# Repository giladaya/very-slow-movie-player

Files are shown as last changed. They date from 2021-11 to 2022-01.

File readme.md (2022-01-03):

# Very Slow Movie Player

I was inspired by [this article](https://debugger.medium.com/how-to-build-a-very-slow-movie-player-in-2020-c5745052e4e4) which was inspired by [that article](https://medium.com/s/story/very-slow-movie-player-499f76c48b62) to build a VSMP.   However, I was put off by the cost of the hardware used in the original designs.  
Eventually found the LILYGO® TTGO T5-4.7 Inch E-paper ESP32 dev board which was cheap and easy to use, at the cost of settling for a smaller display.  
This repo includes the arduino sketch with some supporting info for making your own.

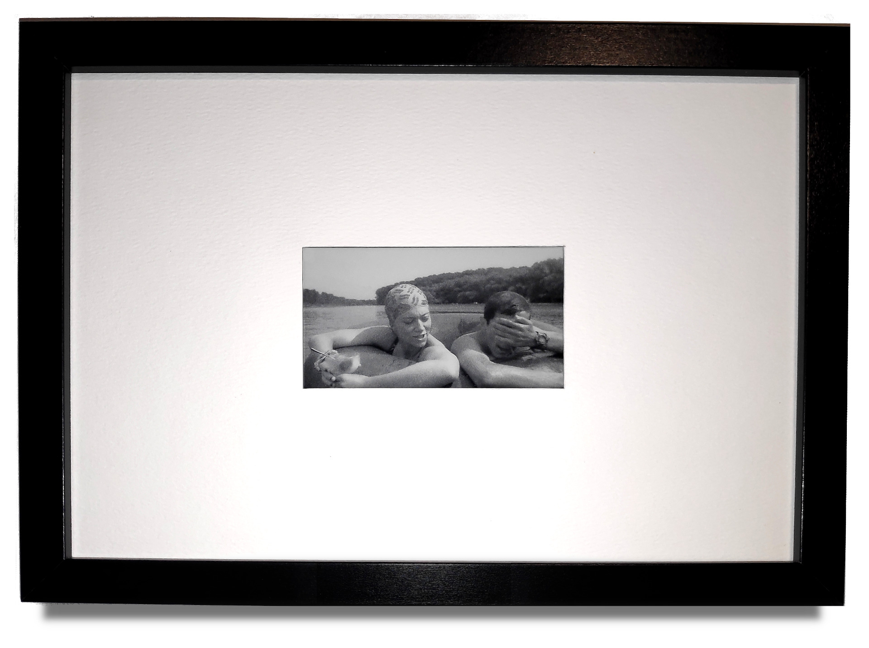
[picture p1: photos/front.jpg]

See photos folder for more photos.

## Features

- Long battery life  
  Uses deep sleep for efficient power use (actual battery life depends on the battery used)
- Resilient  
  The displayed frame position is saved to the SD card from time to time so playback can continue where it stopped after a reset or power loss
- Adaptive drawing  
  A special drawing procedure is used for dark frames for improved visual quality
- Self contained  
  Does not require a network connection or running a server
- Large capacity  
  Can hold hundreds of thousends of pictures (depending on the capacity of SD card used)
- Playlist support  
  Prepare a card with multiple movies by putting each one in a separate folder. They will be played by order one after the other

## Using

1. Setup your machine for development - see the instructions from [here](https://github.com/Xinyuan-LilyGO/LilyGo-EPD47)
2. Install [JPEGDEC library](https://github.com/bitbank2/JPEGDEC)
3. Adjust the configuration parameters at the top of the sketch file to your liking
4. Upload the sketch to the board
5. Prepare an SD card with the desired movies - see instructions below
6. Insert the SD card to the built-in reader
7. Connect a battery
8. Very slow playback of the movies will start
9. Put it somewhere nice and enjoy

## Generating the images

### TL;DR
In the `scripts` folder there are a couple of bash scripts that:
- Extract frames from video
- Apply color corrections
- Remove blank frames  

You can use them like so:

```bash
$ scripts/01_extract.sh video.file.name.mp4 00:24 02:01:07
$ scripts/02_clean.sh
$ scripts/03_resequence.sh
```

### More details
The firmware looks for frames named with a specific pattern, in folders under the root of the SD card file system.  
For example: `/movie_a/000001.jpg`, `/movie_a/000002.jpg`, `/movie_a/000003.jpg` etc.  
The files have to be named sequentially with no gaps and use 6 digits, zero-padded numbers.

The JPEG decoder expects a grayscale color space and _no progressive_ encoding.

These commands worked for me on a Linux system, using `ffmpeg` (version 4.2.4) and `imagemagick` (version 6.9.10):

```bash
# In the directory that contains the video file
mkdir frames

# Use ffmpeg to:
# - Extract frames as files with proper names
# - Scale and crop to 960x540 pixels
# - Apply curves adjustment
$ ffmpeg -ss 00:24 -to 02:01:07 -i video.file.name.mp4 -vf "scale=-2:540,crop=960:540,eq=saturation=0,lutrgb='r=clipval:g=clipval:b=clipval',curves=all='0/0 0.06/0.23 0.13/0.41 0.200/0.55 0.37/0.70 0.63/0.84 1/1'" -r 1 -qscale:v 2 frames/%06d.jpg

# Use mogrify from imagemagick
# to apply a grayscale colorspace for the frames
$ mogrify -colorspace Gray -quality 90 frames/*.jpg
```

Note the use of curves filter for improved quality when displayed on the e-ink screen.

## BOM (2021)

- [LILYGO® TTGO T5-4.7](https://www.aliexpress.com/item/1005002006058892.html)
- [SD card module](https://www.aliexpress.com/item/1005002317501092.html)
- 3.7v Li-Po battery (the larger the better), [example](https://www.aliexpress.com/item/4001116123943.html)
- A picture frame
- Some foam board for mounting the display in the picture frame

Total cost: about $65

## Battery life
With a 6Ah battery and 150 seconds between frame changes:
- 19.5 days to "battery low" indicator
- 20.5 days to battery dead
- 7 hours charging to a full battery

## Future plans
Make it work with a bigger screen!  
There are available unexpensive displays that could be used (EG ED060XC3), but I still don't know how to drive them with available hardware.

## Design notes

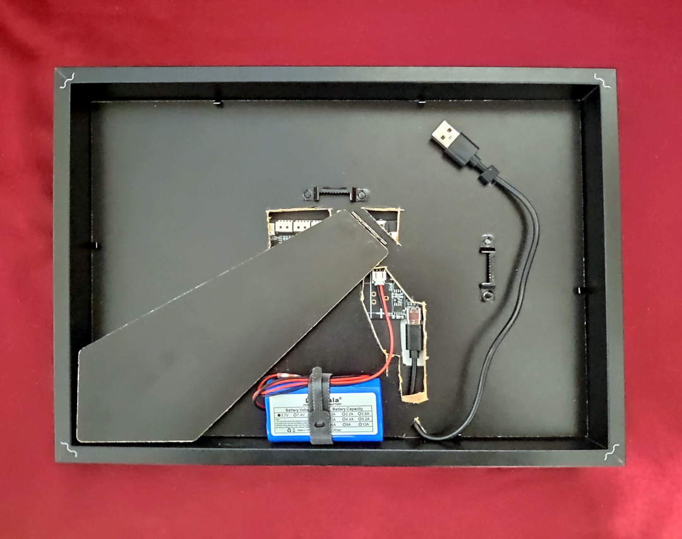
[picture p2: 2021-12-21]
photos/back_cover.jpg

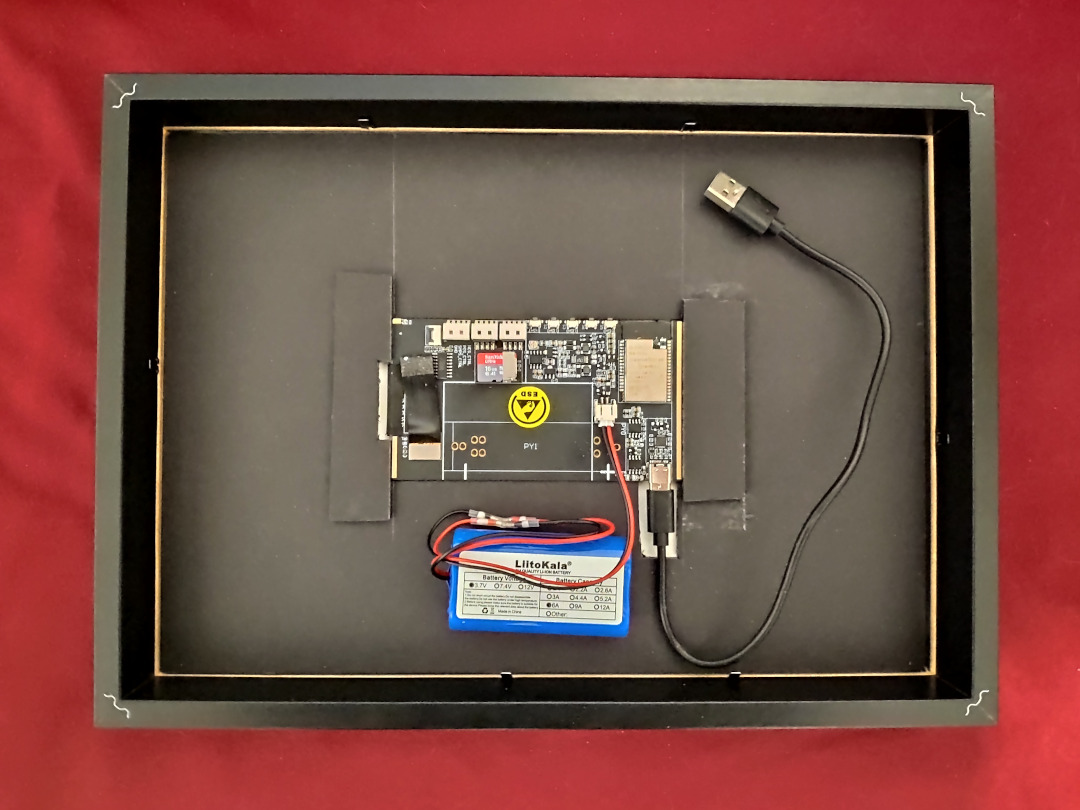
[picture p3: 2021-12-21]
photos/back_board.jpg

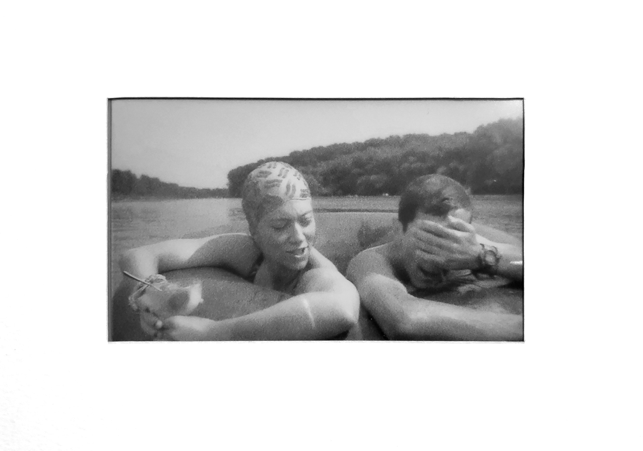
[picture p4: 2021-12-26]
photos/front_close.jpg

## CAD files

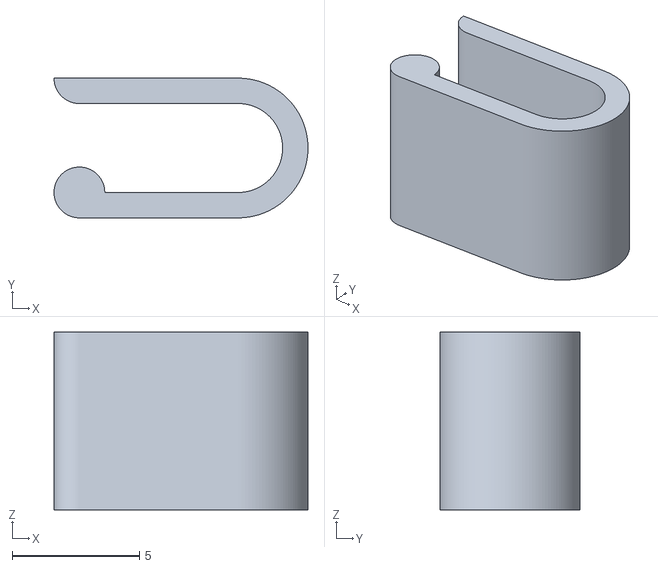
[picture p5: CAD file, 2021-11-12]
printables/cable-holder.stl
10.00 x 5.50 x 7.00

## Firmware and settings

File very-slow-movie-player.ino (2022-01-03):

#ifndef BOARD_HAS_PSRAM
#error "Please enable PSRAM !!!"
#endif

#include <Arduino.h>
#include <SPI.h>
#include <SD.h>
#include "epd_driver.h"

#include "firasans.h"
#include "Filename.h"
#include "MyUtils.h"
#include "JpegUtils.h"
#include "DrawFuncs.h"

#define SD_MISO             12
#define SD_MOSI             13
#define SD_SCLK             14
#define SD_CS               15

// threshold of frame values average to consider a frame as dark
#define DARK_PX_RATIO_TH 0.89

#define uS_TO_S_FACTOR 1000000ULL  /* Conversion factor for micro seconds to seconds */

// Track number of wakeups
RTC_DATA_ATTR int bootCount = 0;

//--------------------
// Config parameters
//--------------------
/*
    Time ESP32 will go to sleep in seconds
    (larger values - longer battery life)
*/
#define TIME_TO_SLEEP 300

/*
    How many frames to advance each update
    Value is a matter of taste.
    Lower means more uniform pictures,
    higher gives more variance but some scenes may be missed
*/
#define FRAMES_DELTA 1

/*
   Whether to use high quality screen clearing.
   False: some ghosting may show.
   True: no ghosting but uses more power
*/
#define HQ_CLEAR false //deprecated

/*
   Whether to use different draw logic for dark frames
   False: dark frames look closer to the original but
     details may not show as they are too dark
   True: dark frames look better.
*/
#define DARK_FRAME_ENH true

/*
   How many frames to wait between saving current file number.
   Lower values means less frames will repeat in case of reset
   but more writes to the SD card.
*/
#define SAVE_FILE_NUM_EVERY 50   /* How many frames to wait between saving file number */

//#define SHOW_LOG
//#define SHOW_BARS

// frame buffers
uint8_t *framebuffer;
uint8_t *nframebuffer;

void updateDisplay() {
  // Measure wake time
  volatile uint32_t t1 = millis();

  char logBuf[128];

  //--------------------------
  // Read voltage
  //--------------------------
  volatile float battery_voltage = MyUtils::readVoltage();
  String voltage = "➸ Voltage :" + String(battery_voltage) + "V";
  Serial.println(voltage);

  //--------------------------
  // Read folder name from SD
  //--------------------------
  esp_sleep_wakeup_cause_t wakeup_reason;
  wakeup_reason = esp_sleep_get_wakeup_cause();
  Serial.printf("Wakeup reason %d\n", wakeup_reason);
  if (wakeup_reason == 0) {
    Serial.printf("Wakeup after reset\n");
    // read folder from file
    Filename::readFromSd();
  }

  //--------------------------
  // Init frame buffers
  //--------------------------
  framebuffer = (uint8_t *)heap_caps_malloc(EPD_WIDTH * EPD_HEIGHT / 2, MALLOC_CAP_SPIRAM);
  if (!framebuffer) {
    Serial.println("alloc memory failed !!!");
    //lastError = MEM_ALOC_ERROR;
    while (1);
  }
  memset(framebuffer, 0xFF, EPD_WIDTH * EPD_HEIGHT / 2);

  if (HQ_CLEAR) {
    nframebuffer = (uint8_t *)heap_caps_malloc(EPD_WIDTH * EPD_HEIGHT / 2, MALLOC_CAP_SPIRAM);
    memset(nframebuffer, 0xFF, EPD_WIDTH * EPD_HEIGHT / 2);
  }

  //--------------------------
  // Draw to frame buffers
  //--------------------------
  // First, draw last frame for erasing if needed
  if (HQ_CLEAR) {
    JpegUtils::drawFileToBuffer(Filename::getPath(), nframebuffer);
  }

  // Now draw new frame
  Serial.println("Advancing frame");
  Filename::advance(FRAMES_DELTA);
  if (Filename::fileNumber > 0) {
    Serial.printf("Draw new %s\n", Filename::getPath());
    JpegUtils::drawFileToBuffer(Filename::getPath(), framebuffer);
  } else {
    int cursor_x = 420;
    int cursor_y = 290;
    writeln((GFXfont *)&FiraSans, "The End", &cursor_x, &cursor_y, framebuffer);
  }

  // We persist file details to SD card every SAVE_FILE_NUM_EVERY frames
  // To continue where we stopped in case of power loss
  if (Filename::fileNumber % SAVE_FILE_NUM_EVERY == 0) {
    Filename::writeToSd();
  }

  sprintf(
    logBuf,
    "%s, b# %d, v: %.2f, Err: %d",
    Filename::getPath(),
    bootCount,
    battery_voltage,
    JpegUtils::lastError
  );
  Serial.println(logBuf);

#ifdef SHOW_LOG
  epd_fill_rect(50, 460, 860, 50, 0xff, framebuffer);
  epd_fill_rect(40, 475, 20, 20, 0x00, framebuffer);
  epd_fill_rect(900, 475, 20, 20, 0x00, framebuffer);

  int cursor_x = 60;
  int cursor_y = 500;

  writeln((GFXfont *)&FiraSans, logBuf, &cursor_x, &cursor_y, framebuffer);
#endif

#ifdef SHOW_BARS
  uint8_t c1 = bootCount % 2 ? 0xff : 0x00;
  uint8_t c2 = bootCount % 2 ? 0x00 : 0xff;

  epd_fill_rect(0, 0, 480, 10, c1, framebuffer);
  epd_fill_rect(480, 0, 480, 10, c2, framebuffer);
  epd_fill_rect(0, 530, 480, 10, c2, framebuffer);
  epd_fill_rect(480, 530, 480, 10, c1, framebuffer);
#endif

  // Display low battery indicator if needed
  MyUtils::renderBattery(framebuffer, battery_voltage);

  //--------------------------
  // Draw from frame buffers to display
  //--------------------------
  if (DARK_FRAME_ENH) {
    float dRatio = MyUtils::calcPartialDarkRatio(framebuffer, 20);
    
    if (dRatio > DARK_PX_RATIO_TH) {
      DrawFuncs::drawDark(framebuffer);
    } else {
      DrawFuncs::drawLight(framebuffer);
    }
  } else {
    DrawFuncs::drawLight(framebuffer);
  }

  // Report awake time
  volatile uint32_t t2 = millis();
  Serial.printf("Update took %dms.\n", t2 - t1);
}

void setup()
{
  Serial.begin(115200);

  // Track reboots
  ++bootCount;
  Serial.printf("****** Boot number %d ******\n", bootCount);

  //--------------------------
  // Init SD card
  //--------------------------

  // Note:
  // The order of the following lines is VERY important!

  // 1. Init SPI
  SPI.begin(SD_SCLK, SD_MISO, SD_MOSI);

  // 2. Init EPD
  epd_init();

  // 3. Init SD card
  bool rlst = SD.begin(SD_CS);
  if (rlst) {
    Serial.printf("➸ Detected SdCard insert:%.2f GB\n", SD.cardSize() / 1024.0 / 1024.0 / 1024.0);

    //--------------------
    // Draw new frame
    //--------------------

    // When reading the battery voltage, POWER_EN must be turned on
    epd_poweron();

    updateDisplay();

    // Turn off the power of the entire
    // POWER_EN control and also turn off the blue LED light
    epd_poweroff_all();
  } else {
    Serial.println("SD init failed, restarting");
    ESP.restart();
  }

  //------------------------------
  // Go to sleep
  //------------------------------
  esp_sleep_enable_timer_wakeup(TIME_TO_SLEEP * uS_TO_S_FACTOR);
  Serial.println("Going to sleep now for " + String(TIME_TO_SLEEP) + " Seconds");
  Serial.flush();
  esp_deep_sleep_start();
}

void loop()
{
  return;
}

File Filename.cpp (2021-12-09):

#include "Filename.h"

namespace Filename
{
  char *getPath()
  {
    genFilePath(curFolder, fileNumber, frameFilePath);
    return frameFilePath;
  }

  void readFromSd()
  {
    File myfile = SD.open(FOLDER_FILE);
    if (myfile)
    {
      int pos = 0;
      uint8_t ch;
      while (myfile.available())
      {
        ch = myfile.read();
        if (ch == ',')
        {
          break;
        }
        curFolder[pos++] = ch;
      }

      char temp[16];
      pos = 0;
      while (myfile.available())
      {
        temp[pos++] = myfile.read();
      }
      fileNumber = atoi(temp);

      //https://stackoverflow.com/questions/42602481/how-do-i-write-integers-to-a-micro-sd-card-on-an-arduino
      //myfile.read((byte *)&fileNumber, sizeof(int)); // read 2 bytes

      myfile.close();
      Serial.printf("Read folder from SD %s, %d\n", curFolder, fileNumber);
    }
    else
    {
      Serial.printf("Failed to open file %s\n", FOLDER_FILE);
    }
  }

  void writeToSd()
  {
    File myfile = SD.open(FOLDER_FILE, FILE_WRITE);
    if (myfile)
    {
      // Folder name
      myfile.print(curFolder);

      // Delimiter
      myfile.print(',');

      // Frame number
      // myfile.write((byte *)&fileNumber, sizeof(int)); // write 2 bytes
      myfile.print(fileNumber);

      myfile.close();
      Serial.printf("Saved folder name to SD: %s, %d\n", curFolder, fileNumber);
    }
    else
    {
      Serial.printf("Failed to open file for write %s\n", FOLDER_FILE);
    }
  }
  void advance(uint8_t delta)
  {
    fileNumber += delta;
    genFilePath(curFolder, fileNumber, frameFilePath);

    Serial.print("Check exist "); Serial.println(frameFilePath);
    if (!SD.exists(frameFilePath))
    {
      moveToNextFolder();
    }
  }

  void moveToNextFolder()
  {
    Serial.println("Searching new folder");
    // Reset file counter
    fileNumber = 1;

    // Now need to find the next folder
    File dir = SD.open("/");
    dir.rewindDirectory();

    File entry;
    // Try to find File for curFolder
    Serial.printf("Moving to current folder %s\n", curFolder);
    while (true)
    {
      entry = dir.openNextFile();
      if (!entry || (entry.isDirectory() && strcmp(entry.name(), curFolder) == 0))
      {
        break;
      }
      // Serial.printf("Checked %s, is not %s\n", entry.name(), curFolder);
    }

    if (!entry)
    {
      // current folder was not found, just rollback.
      Serial.println("current folder was not found, just rewind");
      dir.rewindDirectory();
    }
    else
    {
      Serial.printf("current folder found %s\n", entry.name());
    }

    // Now look for a folder with a file we can display
    bool looped = false;

    while (true)
    {
      entry = dir.openNextFile();
      if (!entry)
      {
        // Reached the end of the folder, try to go back to the start
        if (!looped)
        {
          Serial.println("Rewind folder");
          dir.rewindDirectory();
          looped = true;
          continue;
        }
        else
        {
          // We already looped once, so nothing found - give up
          Serial.println("Suitable folder not found");
          break;
        }
      }

      // We are guaranteed to have entry here
      Serial.printf("Checking %s\n", entry.name());
      if (entry.isDirectory())
      {
        genFilePath(entry.name(), fileNumber, frameFilePath);
        if (SD.exists(frameFilePath))
        {
          strlcpy(curFolder, entry.name(), 127);
          Serial.printf("Found new folder %s\n", curFolder);
          // Persist new folder name to SD card
          writeToSd();
          break;
        }
        else
        {
          Serial.printf("File not found %s, moving on\n", frameFilePath);
        }
      }
    }
  }

  void genFilePath(const char *folder, const int fileNumber, char *frameFilePath)
  {
    sprintf(frameFilePath, "%s/%06d.jpg", folder, fileNumber);
  }

  RTC_DATA_ATTR int fileNumber = 0;
  RTC_DATA_ATTR char curFolder[128];
  char frameFilePath[128];
}

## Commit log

2021-10-31 Add basic error reporting and on-screen log
    [slideshow.ino]
2021-11-02 Fix SD issue, adaptive render methods
    [slideshow.ino]
2021-11-06 Add partial frame measuring, arrange code
2021-11-12 Add accesories for mounting in frame
    [cable-holder.stl]
2021-11-29 Erase prev frame with negative, new draw function
2021-11-30 Save current frame details on SD card
2021-12-02 Reset device if SD card init failed
    [slideshow.ino]
2021-12-04 Save frame number in plain text for easy edits
2021-12-09 Improve draw functions
    Improve draw functions to not use previous frame for erasing.
2021-12-12 New logic for decding on dark frames
2021-12-12 Add BOM
2021-12-30 Add battery life results
2022-01-03 Rename sketch to comply with Arduino IDE
